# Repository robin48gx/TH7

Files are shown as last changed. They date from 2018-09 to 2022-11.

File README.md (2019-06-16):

# TH7
Code to read up to seven thermocouple inputs  from the raspberry pi using the SDS TH7 PCB

Enable spi in raspi-config.

Also, if you are running the pi as a user other than 'pi' add yourself to the spi group 
in /etc/group.

Clone the git hub repo here,

    $ git clone https://github.com/robin48gx/TH7.git 

change directory to TH7 and then run

    $ python ssh_terminal_TH7.py

The python file ssh_terminal_TH7.py is a simple terminal program
that displays the microvolts received from
the thermocouples and displays them in centigrade (for `k` type).
It also displays the PCB temperature and  the Vcc (voltage from USB to the pi;
the value is necessary for accurate calculation of microvolts).
It also creates a logging file (called 'TH7.log') showing the voltage supplied to the pi, the 
PCB temperature and the temperature of each connected thermocouple. This logs once per minute.
If logging is required run with nohup, i.e.

    $ nohup python TH7_logger.py > /dev/null & 
    
The logging will then continue on the pi even if the terminal running it is closed.
The LEDs are controlled by the ssh_terminal_TH7.py and by the TH7_logger.py programs, so if they are alternately blinking
this means the logging is continuing.
A script called 'plot_it.sh' will (using gnuplot) take data from the TH7.log file
and present it as a graph.

The python file thermometers_TH7.py adds to this with 
tkinter drawn thermometers. You may need the tkinter python 
modules for this : i.e. apt-get install python-tk.

Feel free to branch off this to make a temperature logger or a web interface.

For h/w 0.4 and above, an open thermocouple connection will display a very low 
micro-volts figure (typically < -7000) which is out of range for most thermocouples
and out of the range that most temperature readings would ever require (its below
abs zero for a k type for instance).
This means open thermocouples can be error flagged (as has been implemented for the
python `k` type thermocouple in this repo).

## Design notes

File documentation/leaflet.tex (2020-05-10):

%\documentclass[a4paper,10pt]{article}
\documentclass[10pt,foldmark]{leaflet}
\renewcommand*\foldmarkrule{.3mm}
\renewcommand*\foldmarklength{5mm}
\usepackage{qrcode}
\usepackage{amsmath}
\usepackage[T1]{fontenc}
\usepackage{textcomp}
\usepackage{mathptmx}
\usepackage[scaled=0.9]{helvet}
\usepackage[utf8]{inputenc}
\usepackage{graphicx}

%opening
\title{S.D.S. TH7: Seven Channel Thermocouple  Pi Hat}
\author{Scientific Data Systems}
\begin{document}
%\thispagestyle{empty} % get rid of page number does not work
\pagenumbering{gobble}
\maketitle
% \begin{abstract}
% This leaflet describes the TH7 generic thermocouple reader pi-hat/PCB for the Raspberry~Pi.
% \end{abstract}

\begin{figure}
 \centering
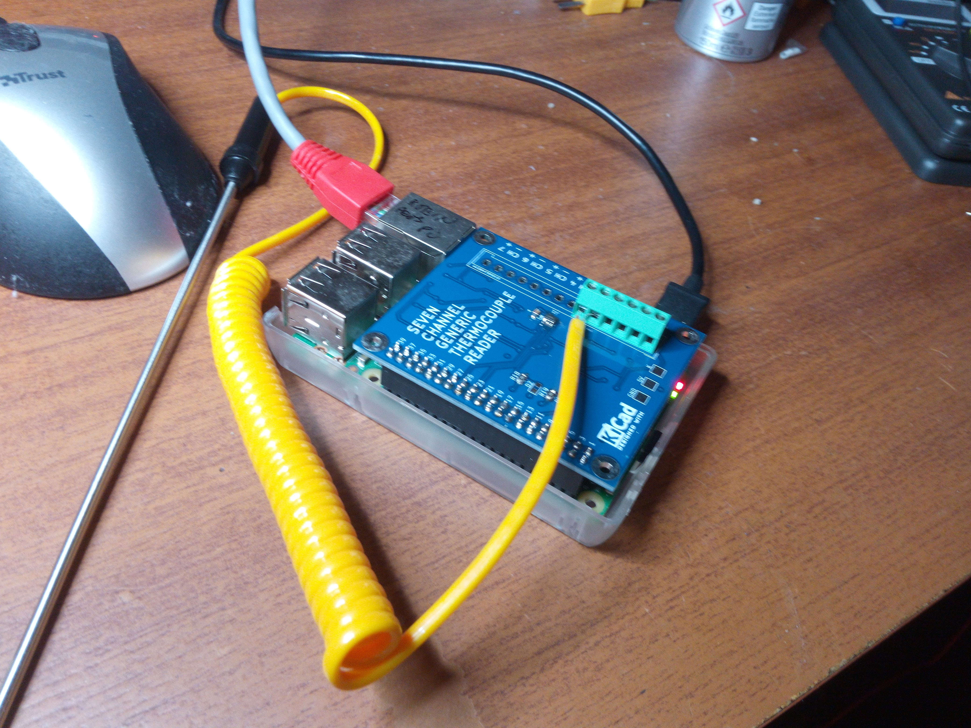
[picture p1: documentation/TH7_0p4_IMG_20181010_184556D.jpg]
 
 % TH7_0p4_IMG_20181010_184556D.jpg: 0x0 pixel, 300dpi, 0.00x0.00 cm, bb=
 \caption{TH7 with a `k' type probe fitted.}
 \label{fig:th7}
\end{figure}

\section{TH7 Description}
%
The TH7 is a Raspberry~Pi hat   that
provides seven thermocouple inputs(see figure~\ref{fig:th7}).
%
This means seven different temperatures can be read
simultaneously. 
%
Its possible uses are 
logging/monitoring and control of temperature sensitive processes.
%
With on-board PCB temperature measurement, 
the PCB temperature
is used to implement
full Cold~Junction~Compensation (CJC).
%
Uncalibrated, the TH7 gives a typical accuracy of $\pm$ ${2}^{\circ} C$.
%
The TH7 also provides two user programmable LEDs; and 
makes available the PCB temperature, and the supply voltage to the Raspberry~Pi (USB voltage can vary between 4.7 to 5.2).
\clearpage
The TH7 is a generic thermocouple reader, and therefore should work with any thermocouple type.
%
Software defines its micro-volt to temperature and CJC characteristics.
Software support has currently only been written for the `k' type.

%\clearpage
\subsection{Characteristics}
The TH7 offers:
\begin{itemize}
 \item Full cold junction compensation;
 \item Thermocouple disconnection or open-circuit  detection;
 \item Seven inputs;
 \item Uses the Rasberry~Pi standard python SPI interface;
 %\item Python coding examples \\ https://github.com/robin48gx/TH7;
 \item Two user programmable LEDs;
 \item On chip PCB temperature measurement;
  \item Can be used as a general-purpose micro-volt 
  reader with a range of $\approx -6000 \mu V \rightarrow 40000 \mu V$.
\end{itemize} 

\section{Instructions}
\subsection{Connection to terminal block}
%
Connect the thermocouples using the hital~tech connectors and ensure the wires make contact with the 
connector metal clamps (see figure~\ref{fig:con}).
%
\subsection{Conection to the device being measured}
%
Always apply insulation to the thermocouples (i.e. do not ground them).
%
Epoxy resin is often useful for gluing thermocouples to devices under long term temperature tests.

\begin{figure}[h]
 \centering
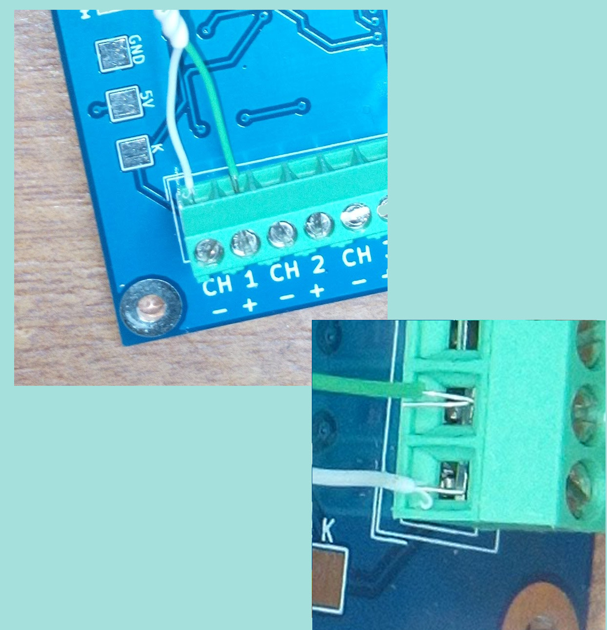
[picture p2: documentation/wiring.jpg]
 
 % wiring.JPG: 0x0 pixel, 300dpi, 0.00x0.00 cm, bb=
 \caption{Image shows wiring for European standard `k' type thermocouples wiring (green is plus and the white is minus; other countries may use different colour schemes.)
%
 If the thermocouple is inserted with incorrect polarity it will read incorrectly and temperature will be seen to go down when heat is applied.}
 \label{fig:con}
\end{figure}

\begin{figure}[h]
 \centering
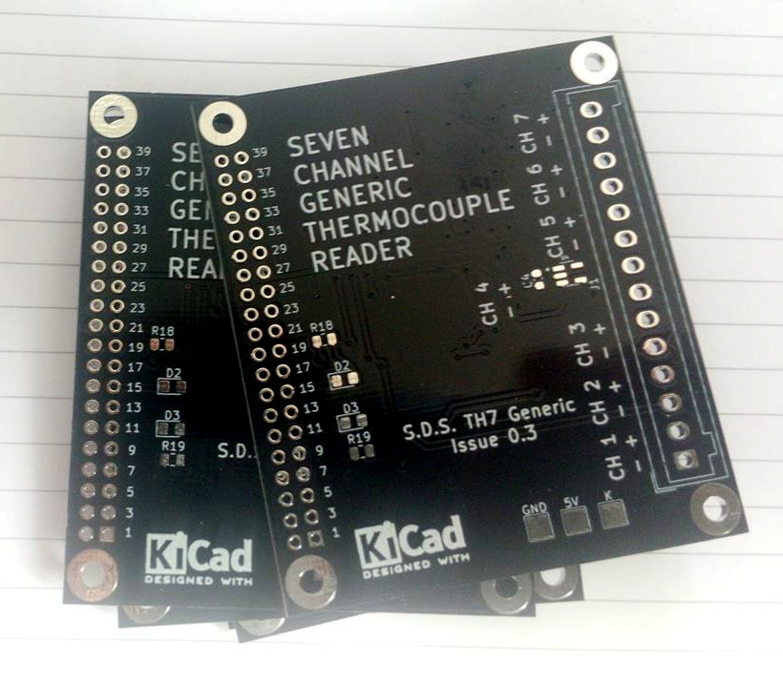
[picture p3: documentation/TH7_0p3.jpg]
 
 % TH7_0p3.jpg: 0x0 pixel, 300dpi, 0.00x0.00 cm, bb=
 \caption{TH7 thermocouple Interface PCB/Raspberry~Pi~Hat}
 \label{fig:th7_2}
\end{figure}

\clearpage
\begin{figure}[ht]
 \centering
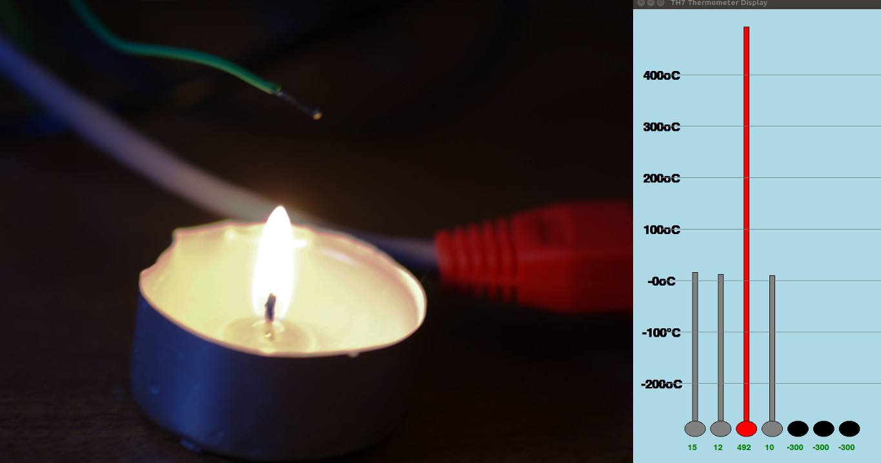
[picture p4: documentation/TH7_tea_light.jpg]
 
 % TH7_tea_light.JPG: 0x0 pixel, 300dpi, 0.00x0.00 cm, bb=
 \caption{Thermocouple over a tea light flame at circa ${500}^{\circ} C$.}
 \label{fig:pi}
\end{figure}
\mbox{}
\\
\\
\qrcode[height=1in]{http://www.scientificdatasystems.co.uk}
\\
\\
\vspace{0.5cm}
Contact: info@scientificdatasystems.co.uk
\\
\\
\qrcode[height=1in]{https://www.youtube.com/watch?v=EcGQWLSwX3U}
\\
\\
Youtube tutorial:
\\
https://www.youtube.com/watch?v=EcGQWLSwX3U
\vspace{0.5cm}
\clearpage

\section{What thermocouples are}

Thermocouples are two different types of metal wire welded together
at one end.
%
When there is a heat difference between two ends of the wire,
the two metals produce a small voltage.
%
This is typically very small, for `k' type thermocouples for instance,
this is about 40 millionths of a Volt per Centigrade change in temperature.
%
This voltage is so small that ordinary voltage reading chips, Analogue to Digital Converters (ADC),  cannot easily read them
to any reasonable accuracy.
%
The small signal is usually amplified
into a range that a computer chip (i.e. ADC) can read.
%
The TH7 has an amplifier that takes the small voltage and amplifies it by 100.
%
It can then be read into the Raspberry~Pi where it can be converted to
a temperature reading with adequate accuracy.
%
Wikipedia has a good entry on thermocouples.
https://en.wikipedia.org/wiki/Thermocouple.
%as a qrcode, \qrcode[height=1in]{https://en.wikipedia.org/wiki/Thermocouple}

\subsection{Cold Junction Compensation}

The tables and equations to convert thermocouple voltage to
temperature all assume that the instrument end is at zero centigrade.

Because the voltage read at the TH7 input is not at zero centigrade (well not normally!)
the junction of the wires {\em at the connector block}  makes a thermocouple itself, but in opposition to
the one at the measurement end.
%
For instance, with a `k' type thermocouple
the voltage read at $25^\circ C$ would read around $1000 \mu V$ low!

The TH7 has a temperature measurement chip placed right by the terminal block for the thermocouple inputs.
By knowing this temperature, the TH7 works out what the missing voltage is
and adds it in before calculating the final temperature. This is commonly known as cold junction compensation.

\subsection{Using the TH7 as a micro-volt reader}

The TH7 can be used as a general purpose micro-volt reader.
The voltage source must be floating i.e. not grounded.
A range of $\approx -6mV \rightarrow 40mV$ can be read.
\clearpage
\subsection{Availability}

TH7 boards are currently available with a four week lead time.
\\
\\
The TH7 is compatible with the Raspberry~Pi models 3 and 4.
\\
\\
TH7 boards may be customised for any thermocouple type.
An example for `k' type may be found on GITHUB 
\\
\\
\\
https://github.com/robin48gx/TH7 
\\
\\
\qrcode{https://github.com/robin48gx/TH7}
%\vspace{3.5cm}
%\clearpage
%\mbox{}
%\vfill
%\qrcode[height=1in]{http://www.scientificdatasystems.co.uk}
%\vspace{0.5cm}
\\
\\
\\
Contact: info@scientificdatasystems.co.uk
\\
\\
\qrcode[height=1in]{http://www.scientificdatasystems.co.uk}
\vspace{0.5cm}

\end{document}

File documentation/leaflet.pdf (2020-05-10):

What thermocouples are

Thermocouples are two different types of metal wire welded together at one end. When there is a heat difference between two ends of the wire, the two metals produce a small voltage. This is typically very small, for ‘k’ type thermocouples for instance, this is about 40 millionths of a Volt per Centigrade change in temperature. This voltage is so small that ordinary voltage reading chips, Analogue to Digital Converters (ADC), cannot easily read them to any reasonable accuracy. The small signal is usually amplified into a range that a computer chip (i.e. ADC) can read. The TH7 has an amplifier that takes the small voltage and amplifies it by 100. It can then be read into the Raspberry Pi where it can be converted to a temperature reading with adequate accuracy. Wikipedia has a good entry on thermocouples. https://en.wikipedia.org/wiki/Thermocouple.

Cold Junction Compensation

The tables and equations to convert thermocouple voltage to temperature all assume that the instrument end is at zero centigrade.

Because the voltage read at the TH7 input is not at zero centigrade (well not normally!) the junction of the wires at the connector block makes a thermocouple itself, but in opposition to the one at the measurement end. For instance, with a ‘k’ type thermocouple the voltage read at 25◦C would read around 1000µV low!

The TH7 has a temperature measurement chip placed right by the terminal block for the thermocouple inputs. By knowing this temperature, the TH7 works out what the missing voltage is and adds it in before calculating the final temperature. This is commonly known as cold junction compensation.

Using the TH7 as a micro-volt reader

The TH7 can be used as a general purpose micro-volt
reader. | The voltage source must be floating i.e. | not
grounded. A range of ≈ −6mV → 40mV can be read.

Availability

TH7 boards are currently available with a four week lead time.

The TH7 is compatible with the Raspberry Pi models 3 and 4.

TH7 boards may be customised for any thermocouple type. An example for ‘k’ type may be found on GITHUB

https://github.com/robin48gx/TH7

Contact: info@scientificdatasystems.co.uk

# S.D.S. TH7: Seven Channel Thermocouple Pi Hat

Scientific Data Systems

May 10, 2020

TH7 Description

The TH7 is a Raspberry Pi hat that provides seven thermocouple inputs(see figure 1). This means seven different temperatures can be read simultaneously. Its possible uses are logging/monitoring and control of temperature sensitive processes. With on-board PCB temperature measurement, the PCB temperature is used to implement full Cold Junction Compensation (CJC). Uncalibrated, the TH7 gives a typical accuracy of ± 2

◦C. The TH7 also provides two user programmable LEDs; and makes available the PCB temperature, and the supply voltage to the Raspberry Pi (USB voltage can vary between 4.7 to 5.2).


Figure 1: TH7 with a ‘k’ type probe fitted.

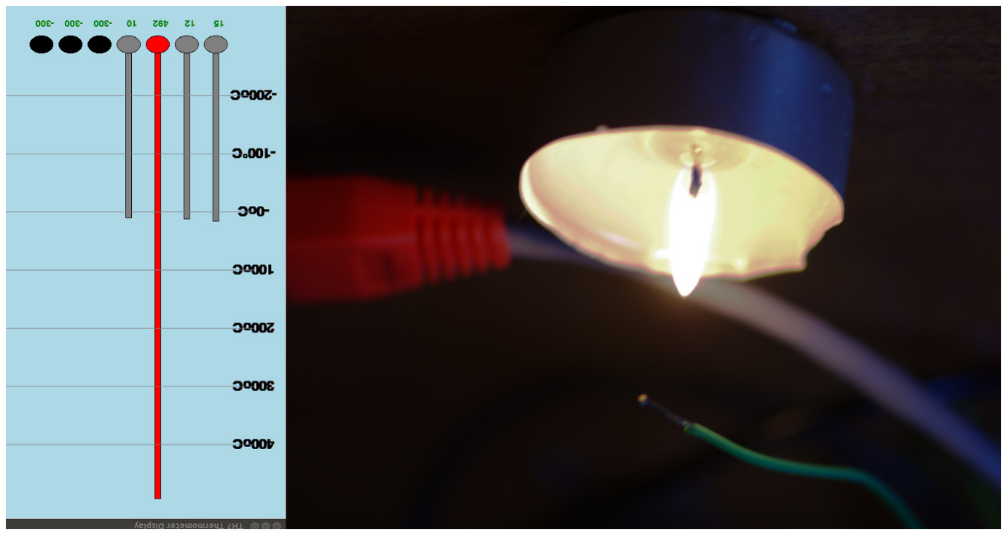
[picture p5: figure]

The TH7 is a generic thermocouple reader, and therefore

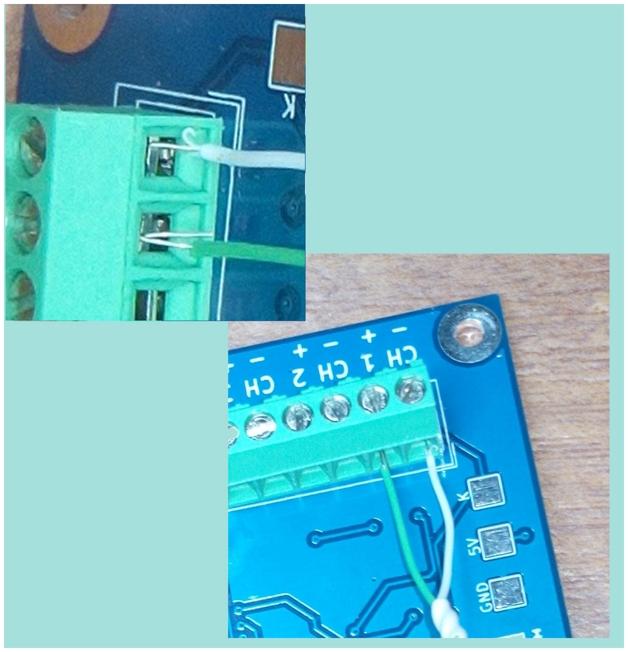
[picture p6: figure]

should work with any thermocouple type. Software defines its micro-volt to temperature and CJC characteristics.

Software support has currently only been written for the ‘k’

type.

Characteristics

The TH7 offers:

Full cold junction compensation; •

Thermocouple disconnection or open-circuit detection; •

Seven inputs; •

Uses the Rasberry Pi standard python SPI interface; •

Two user programmable LEDs; •

On chip PCB temperature measurement; •

Can be used as a general-purpose micro-volt reader with •

. Vµ 40000 →Vµ 6000 ≈ − a range of

Instructions

Connection to terminal block

Connect the thermocouples using the hital tech connectors and ensure the wires make contact with the connector metal

clamps (see figure 2).

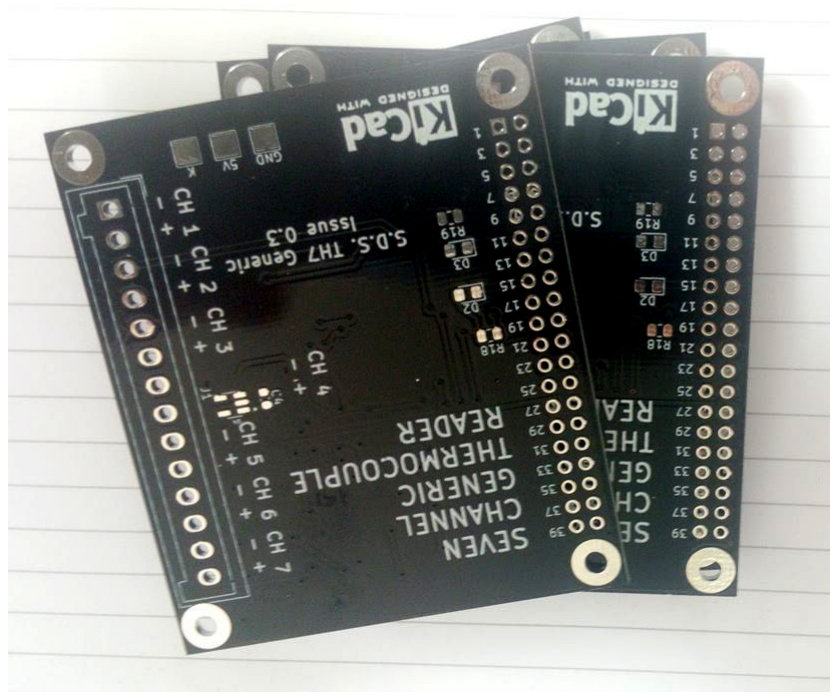
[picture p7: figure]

Conection to the device being measured

Always apply insulation to the thermocouples (i.e. do not ground them). Epoxy resin is often useful for gluing thermocouples to devices under long term temperature tests.

Figure 2: Image shows wiring for European standard ‘k’ type thermocouples wiring (green is plus and the white is minus; other countries may use different colour schemes.)

If the thermocouple is inserted with incorrect polarity it will read incorrectly and temperature will be seen to go down

when heat is applied.

Figure 3: TH7 thermocouple Interface

PCB/Raspberry Pi Hat

Figure 4: Thermocouple over a tea light flame at circa

500◦
. C

Contact: info@scientificdatasystems.co.uk

Youtube tutorial:

https://www.youtube.com/watch?v=EcGQWLSwX3U

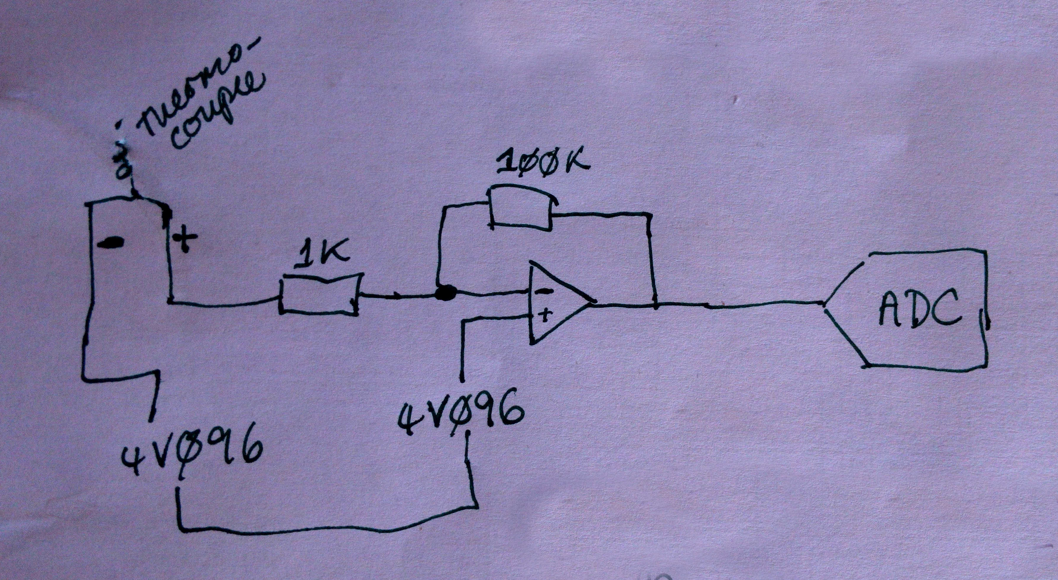
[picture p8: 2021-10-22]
kicad/circuit_drawing.jpg

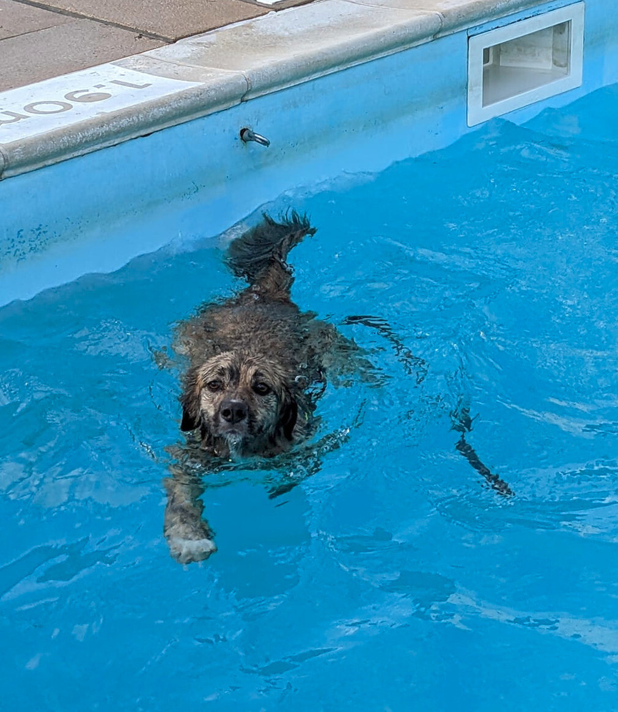
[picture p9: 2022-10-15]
gui_exp/dog.png

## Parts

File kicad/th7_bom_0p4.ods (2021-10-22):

Source: | /home/robin/projects/th7/kicad/test.sch
Date: | Fri 14 Dec 2018 08:12:14 GMT
Tool: | Eeschema 6.0.0-rc1-unknown-46fddab~66~ubuntu16.04.1
Component Count: | 40
ROWS HIGHLIGHTED ARE COMPONENTS MOUNTED ON TOP OF PCB (top has text “SEVEN CHANNEL THERMOCOUPLE READER”) |  |  |  |  |  | Supplied # | Part Code
All resistors are 50ppm per oC and 1%
Ref | Value | Footprint | Datasheet | Manufacturer | Vendor | Num supplied
C1 | 100nF | Capacitor_SMD:C_0603_1608Metric | ~ |  |  | ~=50 | F233-2715
C2 | 100nF | Capacitor_SMD:C_0603_1608Metric | ~ |  |  | “ | “
C3 | 100nF | Capacitor_SMD:C_0603_1608Metric | ~ |  |  | “ | “
C4 | 100nF | Capacitor_SMD:C_0603_1608Metric | ~ |  |  | “ | “
D1 | LM4040DBZ-4.1 | Package_TO_SOT_SMD:SOT-23 | http://www.ti.com/lit/ds/symlink/lm4040-n.pdf |  |  | ~=40 | F1468837RL
D2 | LED_ALT | LED_SMD:LED_0805_2012Metric_Pad1.15x1.40mm_HandSolder | ~ |  |  | 200 | Rs861-0175
D3 | LED_ALT | LED_SMD:LED_0805_2012Metric_Pad1.15x1.40mm_HandSolder | ~ |  |  | 200 | Rs692-1170
J1 | Screw_Terminal_01x14 | Connector_Wago:Wago_734-144_1x14_P3.50mm_Vertical | ~ |  |  | 7 && 6 | HITAL TECH MTS-06008 && 2 times MTS-02008
R1 | 680 Ohm (or 470) | Resistor_SMD:R_0805_2012Metric | ~ |  |  | 1000 | RS804-6423
R2 | 10k | Resistor_SMD:R_0805_2012Metric | ~ |  |  | 100 | F150-0664
R3 | 10k | Resistor_SMD:R_0805_2012Metric | ~ |  |  | “ | “
R4 | 100K | Resistor_SMD:R_0805_2012Metric | ~ |  |  | 100 | F150-0665
R5 | 100K | Resistor_SMD:R_0805_2012Metric | ~ |  |  | “ | “
R6 | 100K | Resistor_SMD:R_0805_2012Metric | ~ |  |  | “ | “
R7 | 100K | Resistor_SMD:R_0805_2012Metric | ~ |  |  | “ | “
R8 | 100K | Resistor_SMD:R_0805_2012Metric | ~ |  |  | “ | “
R9 | 100K | Resistor_SMD:R_0805_2012Metric | ~ |  |  | “ | “
R10 | 100K | Resistor_SMD:R_0805_2012Metric | ~ |  |  | “ | “
R11 | 1K | Resistor_SMD:R_0805_2012Metric | ~ |  |  | 100 | F150663
R12 | 1k | Resistor_SMD:R_0805_2012Metric | ~ |  |  | “ | “
R13 | 1k | Resistor_SMD:R_0805_2012Metric | ~ |  |  | “ | “
R14 | 1k | Resistor_SMD:R_0805_2012Metric | ~ |  |  | “ | “
R15 | 1k | Resistor_SMD:R_0805_2012Metric | ~ |  |  | “ | “
R16 | 1k | Resistor_SMD:R_0805_2012Metric | ~ |  |  | “ | “
R17 | 1k | Resistor_SMD:R_0805_2012Metric | ~ |  |  | “ | “
R18 | 330 | Resistor_SMD:R_0805_2012Metric | ~ |  |  | 150 | F933-4351
R19 | 330 | Resistor_SMD:R_0805_2012Metric | ~ |  |  | “ | “
R25 | 10K | Resistor_SMD:R_0603_1608Metric_Pad1.05x0.95mm_HandSolder | ~ |  |  | ok | F150-0664
R31 | 330k | Resistor_SMD:R_0805_2012Metric | ~ |  |  | ~=50 | F465-2983
R32 | 330k | Resistor_SMD:R_0805_2012Metric | ~ |  |  | “ | F150-0664
R33 | 330k | Resistor_SMD:R_0805_2012Metric | ~ |  |  | “ | “
R34 | 330k | Resistor_SMD:R_0805_2012Metric | ~ |  |  | “ | “
R35 | 330k | Resistor_SMD:R_0805_2012Metric | ~ |  |  | “ | “
R36 | 330k | Resistor_SMD:R_0805_2012Metric | ~ |  |  | “ | “
R37 | 330k | Resistor_SMD:R_0805_2012Metric | ~ |  |  | “ | “
RASPI_2_3_HEADER1 | Raspberry_Pi_2_3 | Connector_PinSocket_2.54mm:PinSocket_2x20_P2.54mm_Vertical | https://www.raspberrypi.org/documentation/hardware/raspberrypi/schematics/rpi_SCH_3bplus_1p0_reduced.pdf |  |  | 9 | RS674-2369
U1 | MCP6074-E_SL | Package_SO:SOIC-14_3.9x8.7mm_P1.27mm | 1.57 USD |  |  | 3 | F1715858
U2 | MCP6074-E_SL | Package_SO:SOIC-14_3.9x8.7mm_P1.27mm | 1.57 USD |  |  | “ | F1715858
U3 | MCP3208 | Package_SO:SOIC-16W_5.3x10.2mm_P1.27mm | http://ww1.microchip.com/downloads/en/DeviceDoc/21298c.pdf |  |  | 0 | F1852020
U4 | TC77 | SOT95P280X145-5N:SOT95P280X145-5N | http://www.ti.com/lit/ds/symlink/tlv700.pdf |  |  | 0 | F1605583
PCB SDS TH7 ver 0.4

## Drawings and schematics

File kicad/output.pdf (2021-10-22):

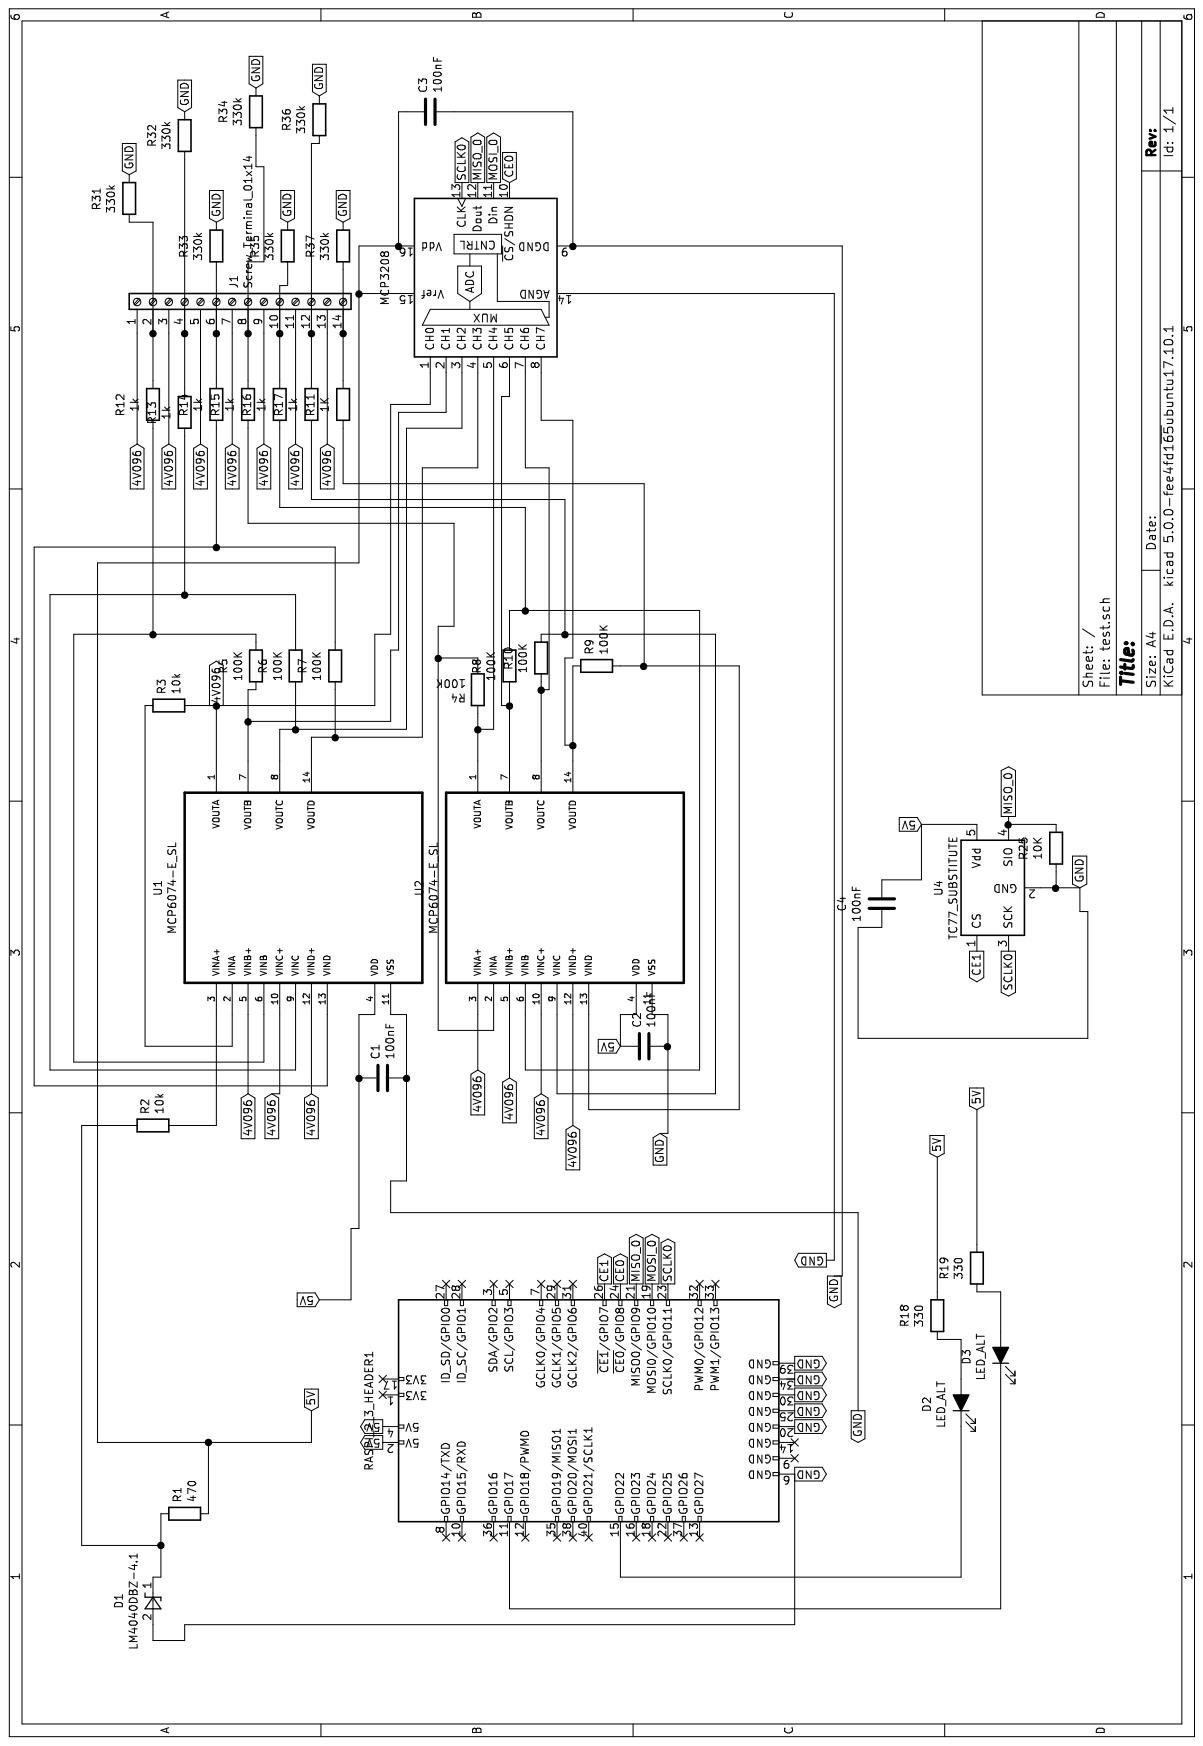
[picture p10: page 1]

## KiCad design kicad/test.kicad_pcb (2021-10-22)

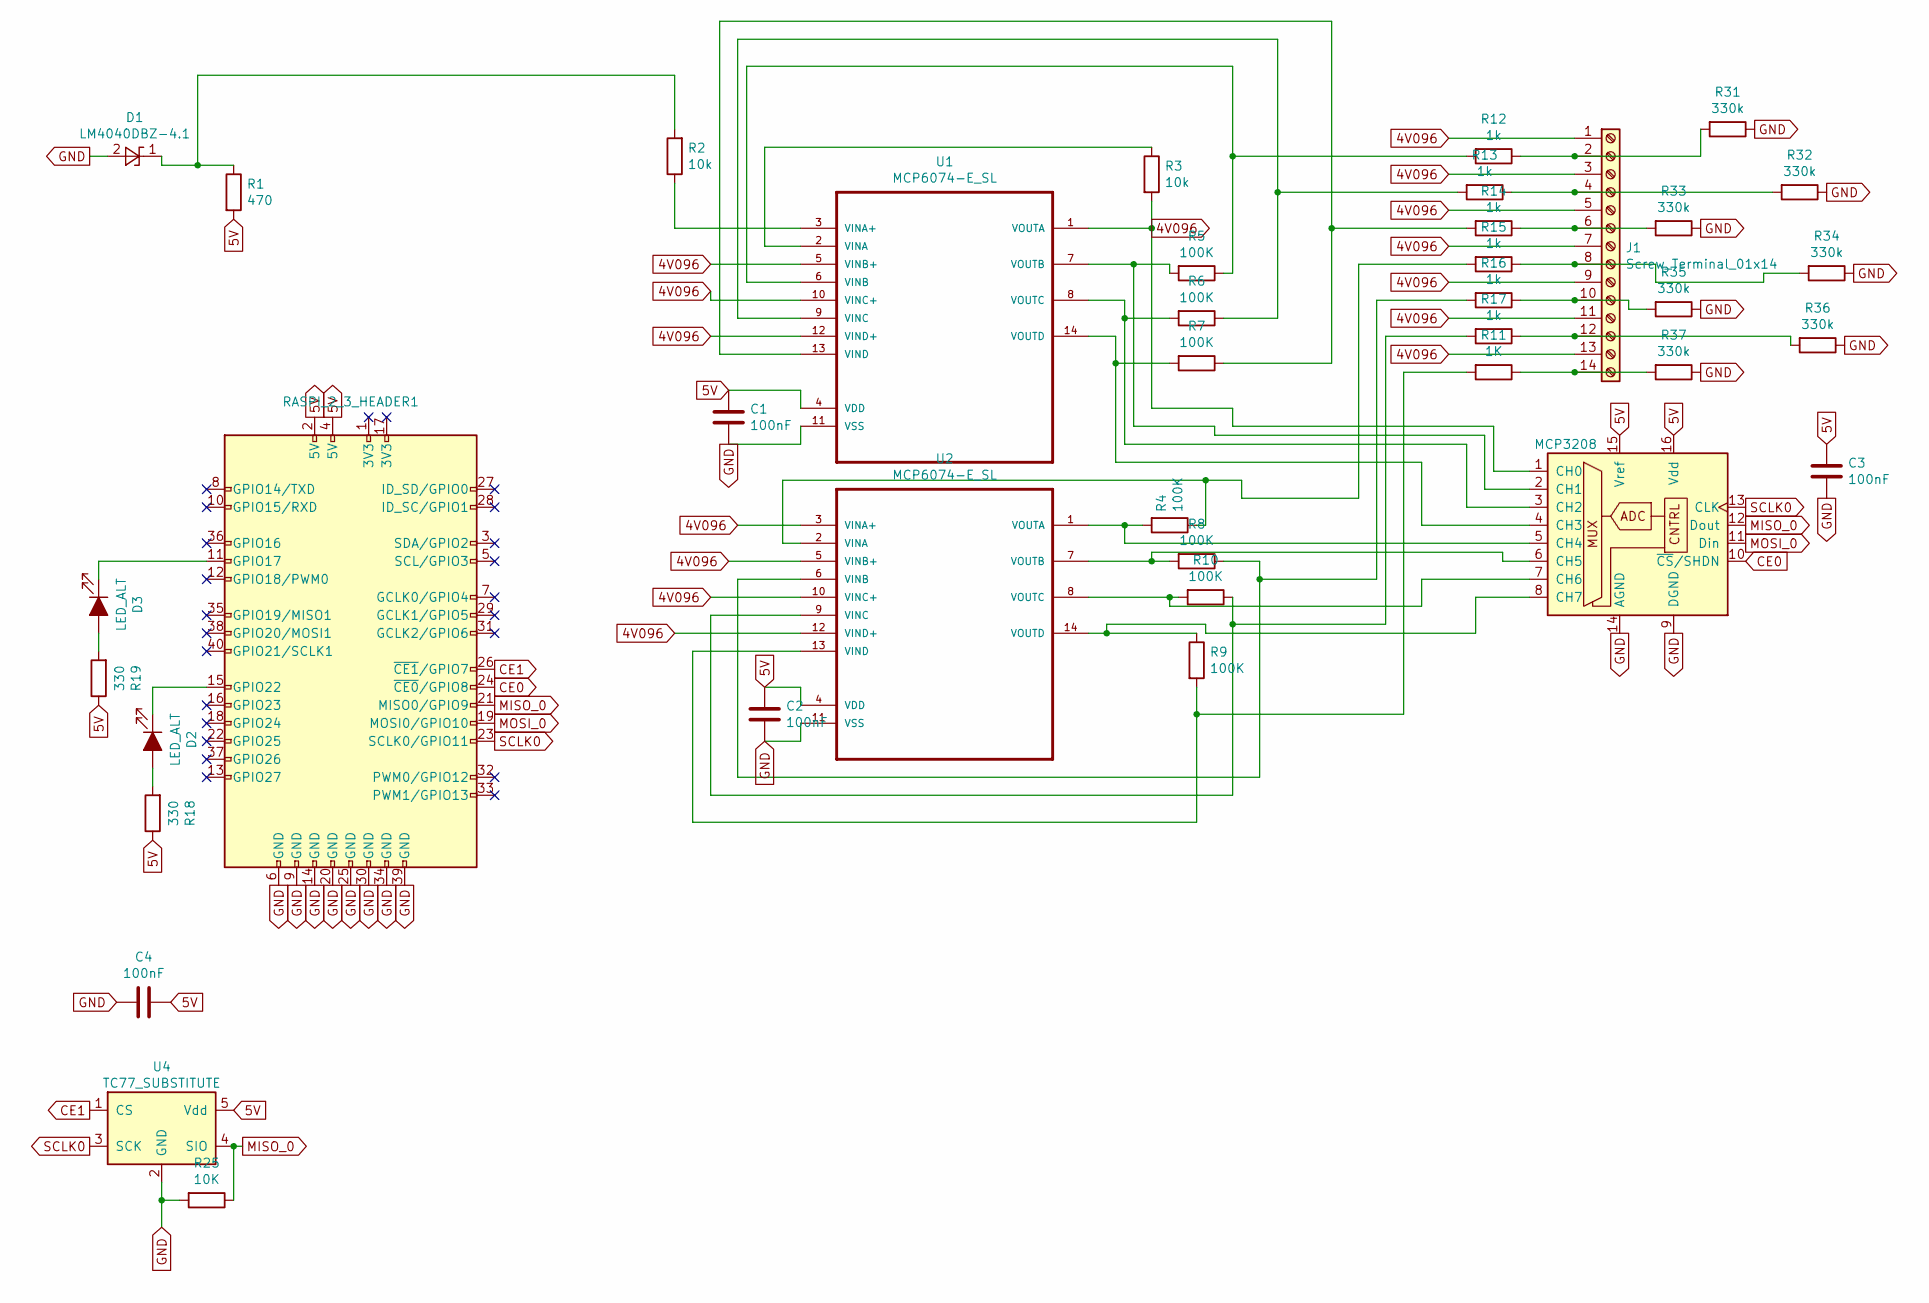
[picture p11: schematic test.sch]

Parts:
C1, C2, C3, C4: 100nF; C_0603_1608Metric
D1: LM4040DBZ-4.1; SOT-23
D2, D3: LED_ALT; LED_0805_2012Metric_Pad1.15x1.40mm_HandSolder
J1: Screw_Terminal_01x14; Wago_734-144_1x14_P3.50mm_Vertical
R1: 470; R_0805_2012Metric
R2, R3: 10k; R_0805_2012Metric
R4, R5, R6, R7, R8, R9, R10: 100K; R_0805_2012Metric
R11: 1K; R_0805_2012Metric
R12, R13, R14, R15, R16, R17: 1k; R_0805_2012Metric
R18, R19: 330; R_0805_2012Metric
R25: 10K; R_0603_1608Metric_Pad1.05x0.95mm_HandSolder
R31, R32, R33, R34, R35, R36, R37: 330k; R_0805_2012Metric
RASPI_2_3_HEADER1: Raspberry_Pi_2_3; PinSocket_2x20_P2.54mm_Vertical
U1, U2: MCP6074-E_SL; SOIC-14_3.9x8.7mm_P1.27mm
U3: MCP3208; SOIC-16W_5.3x10.2mm_P1.27mm
U4: TC77_SUBSTITUTE; SOT95P280X145-5N

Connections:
4V096: J1.1, J1.3, J1.5, J1.7, J1.9, J1.11, J1.13, R3.2, U1.1 (VOUTA), U1.5 (VINB+), U1.10 (VINC+), U1.12 (VIND+), U2.3 (VINA+), U2.5 (VINB+), U2.10 (VINC+), U2.12 (VIND+), U3.1 (CH0); also elsewhere on the board
5V: C1.1, C2.1, C3.1, C4.1, R1.2, R18.1, R19.1, RASPI_2_3_HEADER1.2 (5V), RASPI_2_3_HEADER1.4 (5V), U1.4 (VDD), U2.4 (VDD), U3.15 (Vref), U3.16 (Vdd), U4.5 (Vdd); also elsewhere on the board
CE0: RASPI_2_3_HEADER1.24 (~CE0~/GPIO8), U3.10 (~CS~/SHDN)
CE1: RASPI_2_3_HEADER1.26 (~CE1~/GPIO7), U4.1 (CS)
MISO_0: R25.1, RASPI_2_3_HEADER1.21 (MISO0/GPIO9), U3.12 (Dout), U4.4 (SIO)
MOSI_0: RASPI_2_3_HEADER1.19 (MOSI0/GPIO10), U3.11 (Din)
unnamed: D1.1 (K), R1.1, R2.2
unnamed: D2.1 (K), RASPI_2_3_HEADER1.15 (GPIO22)
unnamed: D2.2 (A), R18.2
unnamed: D3.1 (K), RASPI_2_3_HEADER1.11 (GPIO17)
unnamed: D3.2 (A), R19.2
unnamed: J1.2, R12.1, R31.2
unnamed: J1.4, R13.1, R32.2
unnamed: J1.6, R14.1, R33.2
unnamed: J1.8, R15.1, R34.2
unnamed: J1.10, R16.1, R35.2
unnamed: J1.12, R17.1, R36.2
unnamed: J1.14, R11.1, R37.2
unnamed: R2.1, U1.3 (VINA+)
unnamed: R3.1, U1.2 (VINA)
unnamed: R4.2, U2.1 (VOUTA), U3.5 (CH4)
unnamed: R5.2, U1.7 (VOUTB), U3.2 (CH1)
unnamed: R6.2, U1.8 (VOUTC), U3.3 (CH2)
unnamed: R7.2, U1.14 (VOUTD), U3.4 (CH3)
unnamed: R8.2, U2.7 (VOUTB), U3.6 (CH5)
unnamed: R9.1, U2.14 (VOUTD), U3.8 (CH7)
unnamed: R10.1, R17.2, U2.9 (VINC)
unnamed: R10.2, U2.8 (VOUTC), U3.7 (CH6)
unnamed: R9.2, R11.2, U2.13 (VIND)
unnamed: R5.1, R12.2, U1.6 (VINB)
unnamed: R6.1, R13.2, U1.9 (VINC)
unnamed: R7.1, R14.2, U1.13 (VIND)
unnamed: R4.1, R15.2, U2.2 (VINA)
unnamed: R8.1, R16.2, U2.6 (VINB)
SCLK0: RASPI_2_3_HEADER1.23 (SCLK0/GPIO11), U3.13 (CLK), U4.3 (SCK)

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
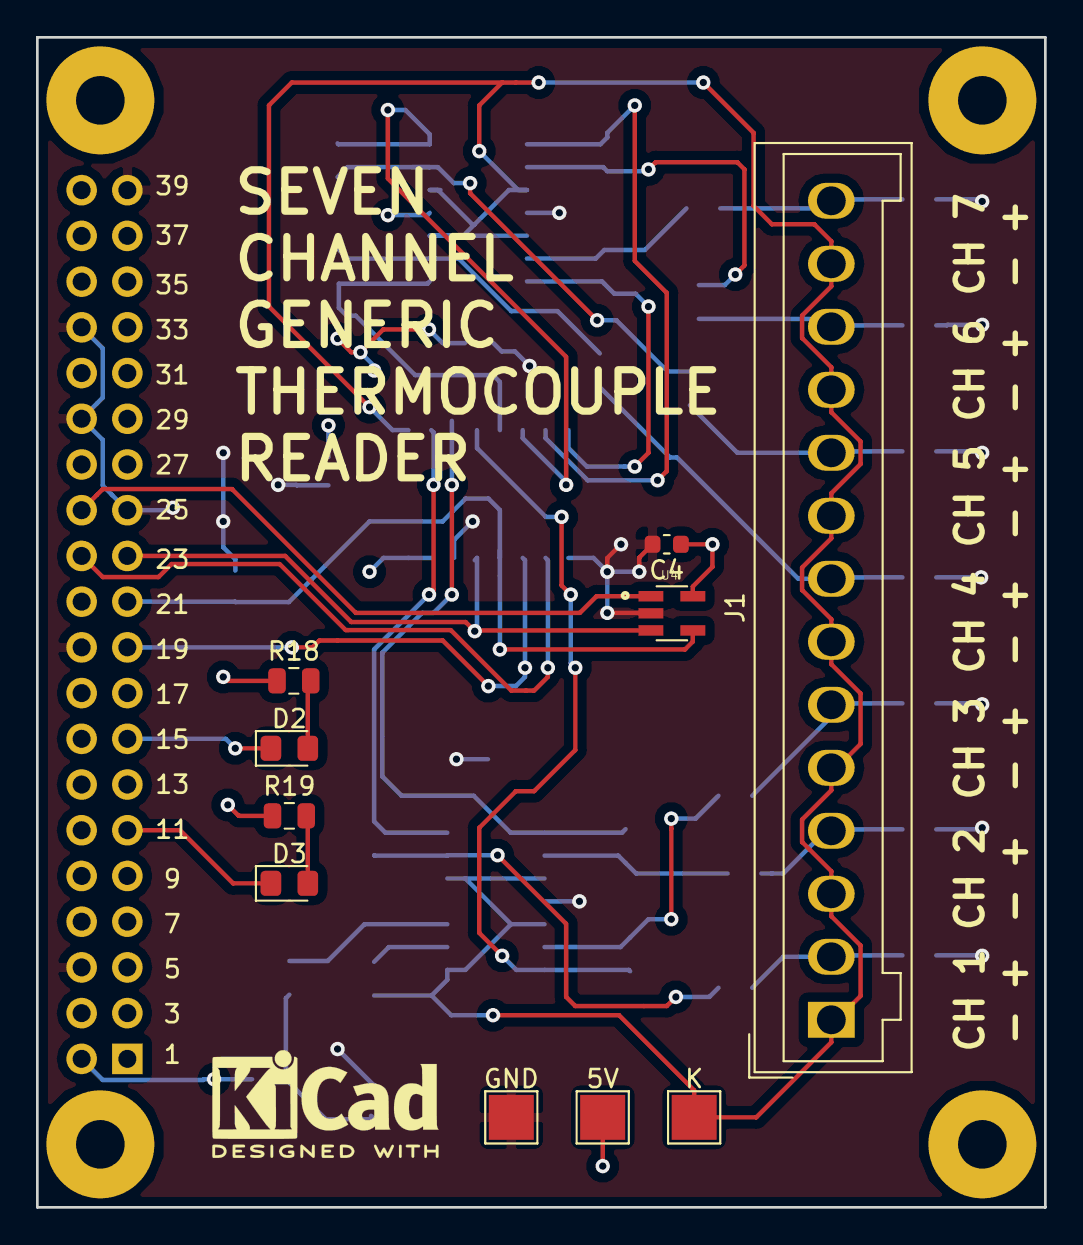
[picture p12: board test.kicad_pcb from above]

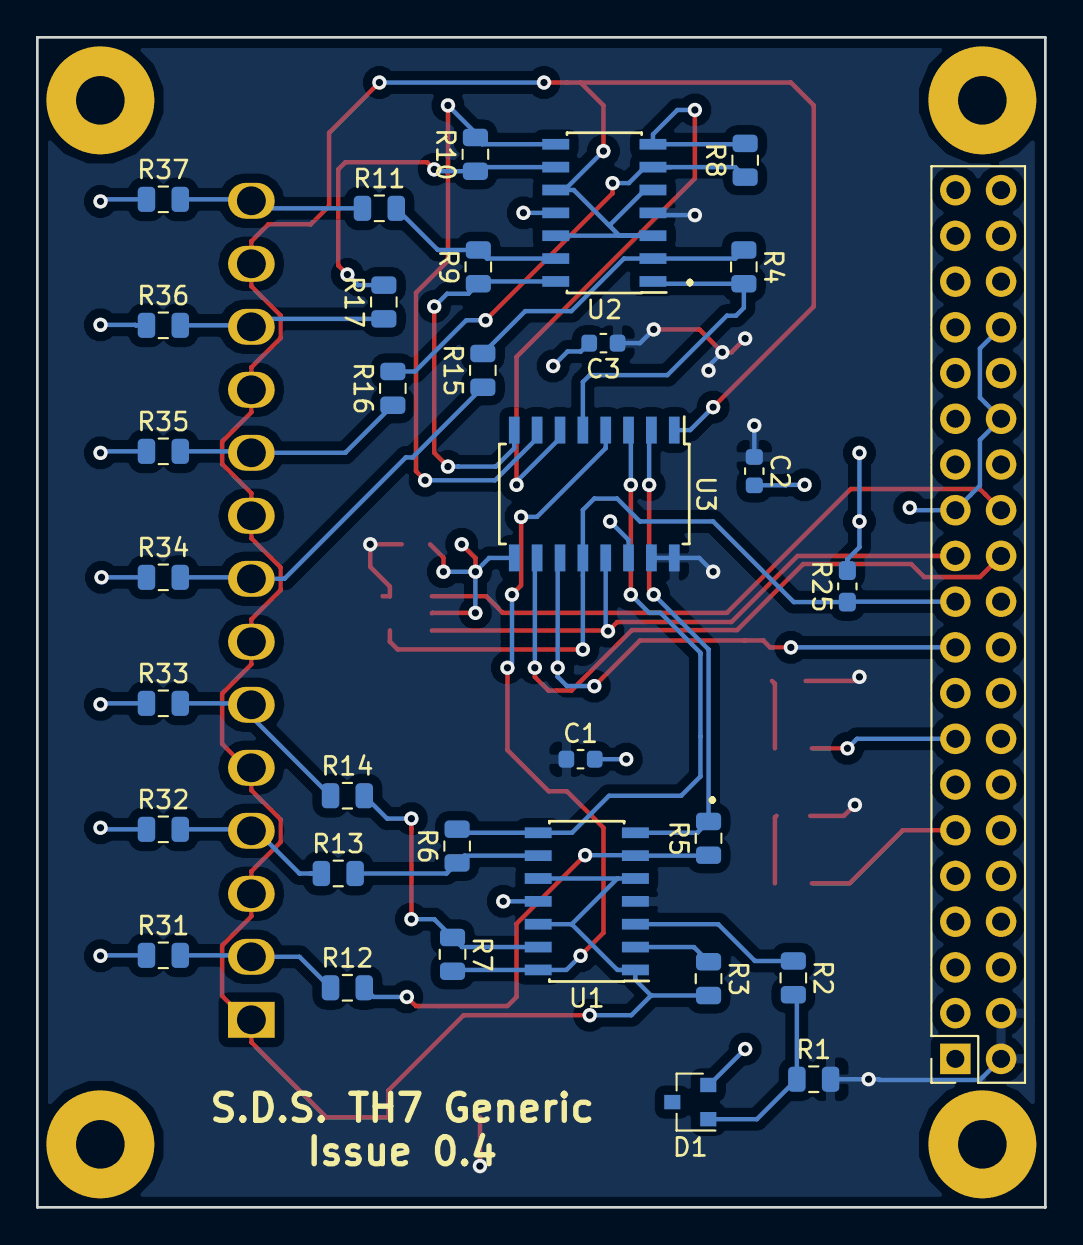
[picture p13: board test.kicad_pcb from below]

Board: 2 copper layers, 56.0 x 65.0 mm, 43 parts (33 on the bottom side), 36 nets.

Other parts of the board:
5V: TestPoint_Pad_2.5x2.5mm
GND: TestPoint_Pad_2.5x2.5mm
K: TestPoint_Pad_2.5x2.5mm

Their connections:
4V096: K.1; also elsewhere on the board
5V: 5V.1; also elsewhere on the board

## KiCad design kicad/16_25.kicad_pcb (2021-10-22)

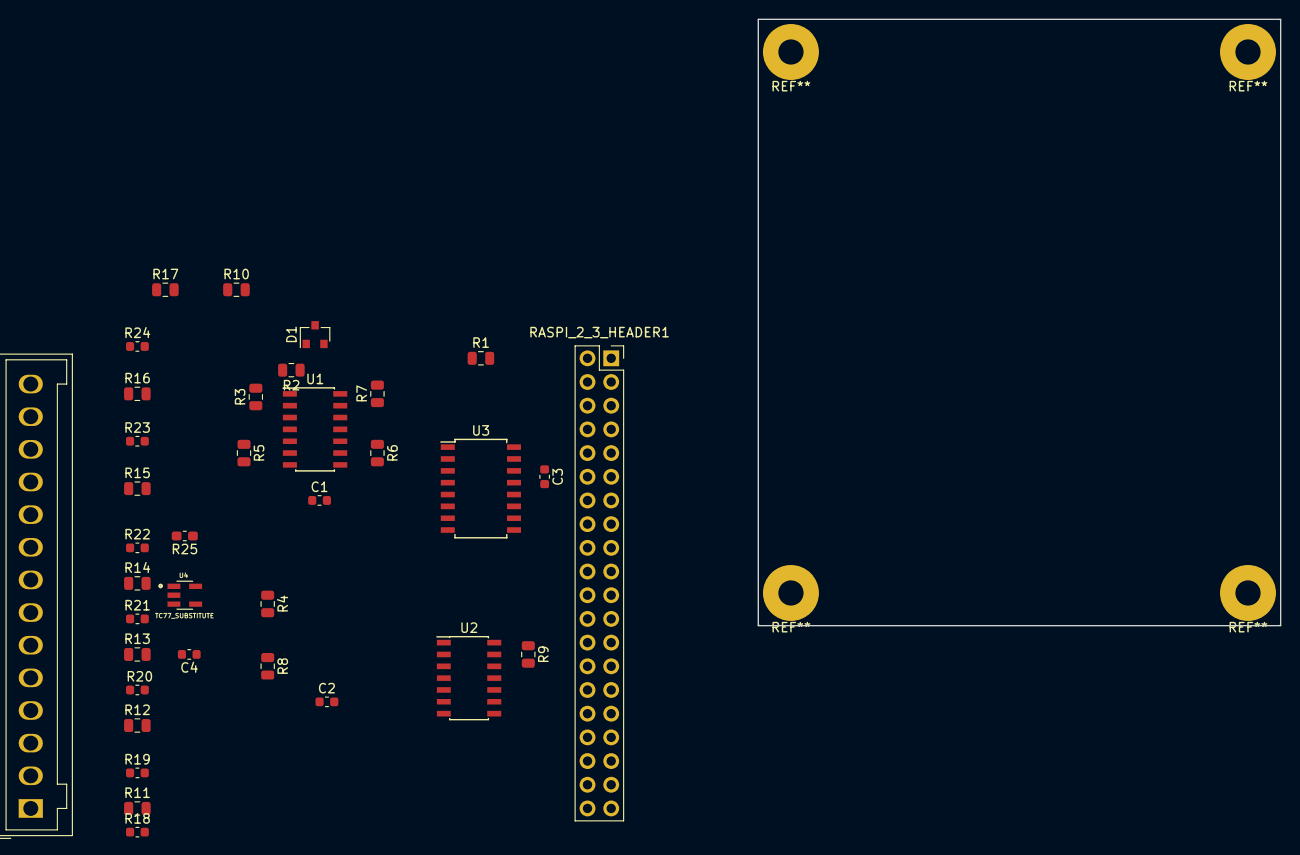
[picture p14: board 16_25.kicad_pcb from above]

Board: 2 copper layers, 56.0 x 65.0 mm, 36 parts (0 on the bottom side), 44 nets, no tracks yet.

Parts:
C1, C2, C3, C4: 100nF; C_0603_1608Metric
D1: LM4040DBZ-4.1; SOT-23
J1: Screw_Terminal_01x14; Wago_734-144_1x14_P3.50mm_Vertical
R1: 470; R_0805_2012Metric
R2, R3: 10k; R_0805_2012Metric
R4: 200K; R_0805_2012Metric
R5, R6, R7: 100K; R_0805_2012Metric
R8, R10: 200k; R_0805_2012Metric
R9: 500k; R_0805_2012Metric
R11: 1K; R_0805_2012Metric
R12, R13, R14, R15, R16, R17: 1k; R_0805_2012Metric
R18, R19, R20, R21, R22, R23, R24: 500K; R_0603_1608Metric
R25: 10K; R_0603_1608Metric_Pad1.05x0.95mm_HandSolder
RASPI_2_3_HEADER1: Raspberry_Pi_2_3; PinSocket_2x20_P2.54mm_Vertical
U1, U2: MCP6074-E_SL; SOIC-14_3.9x8.7mm_P1.27mm
U3: MCP3208; SOIC-16W_5.3x10.2mm_P1.27mm
U4: TC77_SUBSTITUTE; SOT95P280X145-5N

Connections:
4V096: R3.2, R18.2, R19.2, R20.2, R21.2, R22.2, R23.2, R24.2, U1.1, U1.5, U1.10, U1.12, U2.3, U2.5, U2.10, U2.12, U3.1
unnamed: C1.1, C2.1, RASPI_2_3_HEADER1.4, RASPI_2_3_HEADER1.39, U1.4, U2.4
unnamed: C1.2, C2.2, RASPI_2_3_HEADER1.25, U1.11, U2.11
unnamed: C3.1, C4.1, R1.2, RASPI_2_3_HEADER1.2, U3.15, U3.16, U4.5
unnamed: C3.2, RASPI_2_3_HEADER1.30, U3.9
unnamed: C4.2, R25.2, RASPI_2_3_HEADER1.20, U4.2
unnamed: D1.1, R1.1, R2.2
unnamed: D1.2, RASPI_2_3_HEADER1.6
unnamed: J1.1, R18.1
unnamed: J1.2, R11.1
unnamed: J1.3, R19.1
unnamed: J1.4, R12.1
unnamed: J1.5, R20.1
unnamed: J1.6, R13.1
unnamed: J1.7, R21.1
unnamed: J1.8, R14.1
unnamed: J1.9, R22.1
unnamed: J1.10, R15.1
unnamed: J1.11, R23.1
unnamed: J1.12, R16.1
unnamed: J1.13, R24.1
unnamed: J1.14, R17.1
unnamed: R2.1, U1.3
unnamed: R3.1, U1.2
unnamed: R4.1, U2.1, U3.5
unnamed: R5.2, U1.7, U3.2
unnamed: R6.2, U1.8, U3.3
unnamed: R7.2, U1.14, U3.4
unnamed: R8.2, U2.7
unnamed: R9.1, U2.14
unnamed: R10.1, R17.2, U2.9, U3.7
unnamed: R10.2, U2.8
unnamed: R9.2, R11.2, U2.13, U3.8
unnamed: R5.1, R12.2, U1.6
unnamed: R6.1, R13.2, U1.9
unnamed: R7.1, R14.2, U1.13
unnamed: R4.2, R15.2, U2.2
unnamed: R8.1, R16.2, U2.6, U3.6
unnamed: R25.1, RASPI_2_3_HEADER1.21, U3.12, U4.4
unnamed: RASPI_2_3_HEADER1.19, U3.11
unnamed: RASPI_2_3_HEADER1.23, U3.13, U4.3
unnamed: RASPI_2_3_HEADER1.24, U3.10
unnamed: RASPI_2_3_HEADER1.26, U4.1
unnamed: RASPI_2_3_HEADER1.34, U3.14

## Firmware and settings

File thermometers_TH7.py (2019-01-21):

#! /usr/bin/python
import sys
import time
import Tkinter	# requires python-tk (apt-get install python-tk)
from Tkinter import *
import random
import math
import os
import spidev
import time
import RPi.GPIO as GPIO

#
# TH7 thermocouple reader for the raspberry pi
#
# The array below `temps' holds the temperatures calculated
# in centigrade
#
temps = [ 20.3,20.3,20.3,20.3,20.3,20.3,20.3 ]

# start of the thermometers at bottom of page
ybase = 600

# set up the I/O to read the thermocouples
#
spi = spidev.SpiDev()  # spi instance to read 12 bit ADC	
spi_tc77 = spidev.SpiDev() # spi instance to read TC77 digital temperature chip
spi.open(0, 0)
spi_tc77.open(0,1)
spi.max_speed_hz =  10000
spi_tc77.max_speed_hz =  10000
# create spi object
# open spi port 0, device (CS) 0
GPIO.setmode(GPIO.BCM)
GPIO.setwarnings(False)
GPIO.setup(22, GPIO.OUT) # D2 LED   
GPIO.setup(17, GPIO.OUT) # D3 LED
GPIO.output(22,GPIO.HIGH) # D2 LED OFF
GPIO.output(17,GPIO.LOW) # D3 LED ON
led_counter=0
pcb_temp = 25.0
channels = [0,0,0,0,0,0,0,0]
vadj =1.0
vadj_now=1.0
vref=0.0
# compress movement for thermometers
#

def tcompress ( t ):
   if t < -55:
      t = ((t+55)/5 - 55)
   if t > 120:
      t = (t/5 + 96)
   return t



# assume kelvin input
#
def tcompressk ( t ):
    return tcompress(t -273.15)*2

# print the micro-volts, voltage supplied to pi and the voltage adjustment factors
# onto a terminal
#
def print_list():
    global pcb_temp
    for i in range(1, len(channels)):
        uv = channels[i] + (k_type_translate_c(pcb_temp))
        if uv < -6500:
          print ('channel: %d\t %.3f uV \t %.3f oC (K-type) ERROR' % (i, uv, k_type_translate_uv(uv))) 
        else:
          print ('channel: %d\t %.3f uV \t %.3f oC (K-type)' % (i, uv, k_type_translate_uv(uv)))
        temps[i-1] = k_type_translate_uv(uv) # for the gui thermomemters
    print "vadj:    \t%2f" % vadj
    print "vadj_now: %2f  Pi Vdd %f" % (vadj_now, 5.0/vadj)
    #print "PCB_TEMP: %2f" % pcb_temp
    print "PCB_TEMP %2foC uV:\t%2f\t(%2f C)" % (pcb_temp,k_type_translate_c(pcb_temp), k_type_translate_uv(k_type_translate_c(pcb_temp)))


# ITS-90 thermocouple polynomial equations to translate temperature oC to microvolts
# for `k' type thermocouples
#
#
def k_type_translate_c(temp):
    c0 =  c1 =  c2 =  c3 =  c4 =  c5 =  c6 =  c7 =  c8 =  c9 =  c10 = 0.0
    t = et = mikrovolts = 0.0

    a0 = 1.185976e2
    a1 = -1.183432e-4

    if (temp < 0.0):
        c0 = 0.0
        c1 = 3.9450128025e1
        c2 = 2.3622373598e-2
        c3 = -3.2858906784e-4
        c4 = -4.9904828777e-6
        c5 = -6.7509059173e-8
        c6 = -5.7410327428e-10
        c7 = -3.1088872894e-12
        c8 = -1.0451609365e-14
        c9 = -1.9889266878e-17
        c10 = -1.6322697486e-20
        et = 0.0
    
    elif(temp >= 0.0 and temp < 13720.0):
        c0 = -1.7600413686e1
        c1 = 3.8921204975e1
        c2 = 1.8558770032e-2
        c3 = -9.9457592874e-5
        c4 = 3.1840945719e-7
        c5 = -5.6072844889e-10
        c6 = 5.6075059059e-13
        c7 = -3.2020720003e-16
        c8 = 9.7151147152e-20
        c9 = -1.2104721275e-23
        c10 = 0.0
        t = (temp)
        t -= 126.9686
        t = t * t
        t = t * a1
        et = math.exp(t) * a0
    else:
        return 0.0
    t = (temp)
    mikrovolts = c0 + t * (c1 + t * (c2 + t * (c3 + t * (c4 + t * (c5 + t * (c6 + t * (c7 + t * (c8 + t * (c9 + t * (c10)))))))))) + et
    return mikrovolts

# ITS-90 k type thermocouple function to translate microvolts to temperature
def k_type_translate_uv(uV):
    c1 = c2 = c3 = c4 = c5 = c6 = c7 = c8 = c9 = 0.0
    temp = 0.0
    if (uV >= -5891.0 and uV < 0.0):
        c0 = 0
        c1 = 2.5173462e-2
        c2 = -1.1662878e-6
        c3 = -1.0833638e-9
        c4 = -8.9773540e-13
        c5 = -3.7342377e-16
        c6 = -8.6632643e-20
        c7 = -1.0450598e-23
        c8 = -5.1920577e-28
        c9 = 0

        temp = c0 + uV * (c1 + uV * (c2 + uV * (c3 + uV * (c4 + uV * (c5 + uV * (c6 + uV * (c7 + uV * (c8))))))))
    elif (uV >= 0.0 and uV < 20644.0):
        c0 = 0
        c1 = 2.508335e-2
        c2 = 7.860106e-8
        c3 = -2.503131e-10
        c4 = 8.315270e-14
        c5 = -1.228034e-17
        c6 = 9.804036e-22
        c7 = -4.413030e-26
        c8 = 1.057734e-30
        c9 = -1.052755e-35
        
        temp = c0 + uV * (c1 + uV * (c2 + uV * (c3 + uV * (c4 + uV * (c5 + uV * (c6 + uV * (c7 + uV * (c8 + uV * (c9)))))))))


    elif (uV >= 20644.0 and uV < 54886.0):
        c0 = -1.318058e2
        c1 = 4.830222e-2
        c2 = -1.646031e-6
        c3 = 5.464731e-11
        c4 = -9.650715e-16
        c5 = 8.802193e-21
        c6 = -3.110810e-26
        c7 = 0
        c8 = 0
        c9 = 0

        temp = c0 + uV * (c1 + uV * (c2 + uV * (c3 + uV * (c4 + uV * (c5 + uV * (c6))))))
    else:
        temp = -300.0 # OUT OF RANGE deliberately
    return temp




a = 0
ch1_uv = 0.0
result=0

def read_thermocouples():
  # try:
    global a
    global vref
    global vadj
    global led_counter
    global pcb_temp
    a = a + 1
    if a>8:
      os.system("clear") # this is for tunning in a terminal over ssh on a pi
      a = 0
      print_list()
      #time.sleep(0.1)

    time.sleep(0.01)
    # perpare bits for ADC command to read channel 
    cb1 = 4 + 2 + ((a & 4) >> 2)
    cb2 = (a & 3) << 6
    resp = spi.xfer2([cb1, cb2, 0x00])

    if a == 0:
        vref = resp[1] * 256.0 + resp[2] * 1.0
        vadj_now = vref/3355.4432
        vadj = vadj_now * 0.1 + vadj * 0.9
        print "vref: ", vref, "vadj: ", vadj
        channels[a] = vref

        if led_counter<4: 
          GPIO.output(17,GPIO.LOW) # D3 LED ON
          GPIO.output(22,GPIO.HIGH) # D2 LED OFF
        else:
          GPIO.output(17,GPIO.HIGH) # D3 LED OFF
          GPIO.output(22,GPIO.LOW) # D2 LED ON
        led_counter = led_counter + 1
        if led_counter>8:
           led_counter=0
    if a >= 1 and a < 8:
        ch1_adc12_5v = ((resp[1] * 256.0 + resp[2]*1.0) - vref) * vadj
        ch1 = resp[1] * 256.0 + resp[2]*1.0
        perfect = ((vref - ch1) * vadj)
        bigV = (perfect/4096.0)*5.0
        # the signal has been amplified G=100 so we need to multiply by 10K
        uV = bigV*10000
        # now first order filter the micro-volts to reduce random noise
        channels[a] = channels[a]*0.9 + 0.1*uV
    if a == 8: # read the temperature from the tc77
    	resp = spi_tc77.xfer2([0x00, 0x00, 0x00, 0x00]) # transfer four bytes
        number = resp[0] * 256 + resp[1]
	pcb_temp = (number/8.0) * 0.0625
	print "Temp: ", pcb_temp, resp

# set up the gui
#
curtime = ''
curtemp = ''
newtemp = -299.0
timeline = [1,2,3,4,5,6,7]
templine = [1,2,3,4,5,6,7]
templine2 = [1,2,3,4,5,6,7]
timeobj = ''
abs_zero = -273.15


class Window:

  def __init__(self,root):
    self.root = root 
    self.canvas = Tkinter.Canvas(self.root)
    self.canvas.pack()
    self.canvas.config(background='lightblue')
    self.canvas.config(width=500)
    self.canvas.config(height=900)


class TH7gui():
	device = None
	handle = None
	def __init__(self,):
		return None

	def open(self):
		return self.handle

update_gui_counter = 0

def update_gui():
  INTERVAL = 1
  global curtime
  global curtemp
  global timeobj
  global newtemp
  global ybase
  global update_gui_counter
  deg = unichr(176).encode("utf-8")
  read_thermocouples()
  update_gui_counter = update_gui_counter + 1
  #print "update_gui_counter", update_gui_counter
  if update_gui_counter >= 10:
    update_gui_counter  = 0 
    for i in range(7):
            #
            #print 'newtemp' , newtemp
            newtemp = temps[i]
            temps[i] += 0.1 * random.randrange(-10, 20)
            if temps[i] > 500:
                temps[i] = -300
            
            if templine2:
              TH7_window.canvas.delete(templine2[i])
              TH7_window.canvas.delete(templine[i])
            t1 = " %2.2d " % newtemp
            kelvin = newtemp + (-abs_zero);
            
            
            if kelvin >= 273.15 + 40:
              filc = 'pink' # warm
            if kelvin >= 273.15 + 70: # 120oC
              filc = 'red' # hot
            if kelvin < 273.15 + 35:
              filc = 'orange' # human levels of body temperature, go orange
            if kelvin < 273.15 + 24:
              filc = 'grey' # coldish
            if kelvin < 273.15:
              filc = 'blue' # cold
            if kelvin < -15+273.15:
              filc = 'black' # very very cold, like sweden in the winter cold
            
            x1 = 115 + i * 50
            x2 = 125 + i * 50
            y1 =  (ybase)
            y2 = (ybase)-tcompressk(kelvin)
            #y2 =  (ybase)-kelvin
            #print " x1 ",x1, " y1 ", y1, " x2 ", x2, " y2 ", y2
            templine[i] = TH7_window.canvas.create_text(x1, y1+250, text=t1, font=("Helvetica", "12", "bold"), fill='green')
            templine2[i] = TH7_window.canvas.create_rectangle(x1, y1, x2,  y2, fill=filc)
            
            #tll = TH7_window.canvas.create_oval( x1-15, 800+30, x1+25, 800, fill=filc)
    
    #
    #
    y1pos = ybase - tcompressk(0.0)
    templine3 = TH7_window.canvas.create_text ( 55, y1pos, text="-273.15", font=("Helvetica", "18", "bold"), fill='black') 
    templine4 = TH7_window.canvas.create_line ( 55, y1pos, 700, y1pos, fill='grey')
    #
    y1pos = ybase - tcompressk(273.15-200.0)
    templine3 = TH7_window.canvas.create_text ( 55, y1pos, text="-200oC", font=("Helvetica", "18", "bold"), fill='blue') 
    templine4 = TH7_window.canvas.create_line ( 55, y1pos, 700, y1pos, fill='grey')
    #
    y1pos = ybase - tcompressk(273.15-100.0)
    templine3 = TH7_window.canvas.create_text ( 55, y1pos, text="-100"+deg+"C", font=("Helvetica", "18", "bold"), fill='blue') 
    templine4 = TH7_window.canvas.create_line ( 55, y1pos, 700, y1pos, fill='grey')
    #
    y1pos = ybase - tcompressk(273.15-0.0)
    templine3 = TH7_window.canvas.create_text ( 55, y1pos, text="-0oC", font=("Helvetica", "18", "bold"), fill='black') 
    templine4 = TH7_window.canvas.create_line ( 55, y1pos, 700, y1pos, fill='grey')
    #
    y1pos = ybase - tcompressk(273.15+100.0)
    templine3 = TH7_window.canvas.create_text ( 55, y1pos, text="100oC", font=("Helvetica", "18", "bold"), fill='black') 
    templine4 = TH7_window.canvas.create_line ( 55, y1pos, 700, y1pos, fill='grey')
    #
    y1pos = ybase - tcompressk(273.15+200.0)
    templine3 = TH7_window.canvas.create_text ( 55, y1pos, text="200oC", font=("Helvetica", "18", "bold"), fill='red') 
    templine4 = TH7_window.canvas.create_line ( 55, y1pos, 700, y1pos, fill='grey')
    #
    y1pos = ybase - tcompressk(273.15+300.0)
    templine3 = TH7_window.canvas.create_text ( 55, y1pos, text="300oC", font=("Helvetica", "18", "bold"), fill='red') 
    templine4 = TH7_window.canvas.create_line ( 55, y1pos, 700, y1pos, fill='grey')
    #
    y1pos = ybase - tcompressk(273.15+400.0)
    templine3 = TH7_window.canvas.create_text ( 55, y1pos, text="400oC", font=("Helvetica", "18", "bold"), fill='red') 
    templine4 = TH7_window.canvas.create_line ( 55, y1pos, 700, y1pos, fill='grey')
    #
    y1pos = ybase - tcompressk(273.15+600.0)
    templine3 = TH7_window.canvas.create_text ( 55, y1pos, text="600oC", font=("Helvetica", "18", "bold"), fill='red') 
    templine4 = TH7_window.canvas.create_line ( 55, y1pos, 700, y1pos, fill='grey')
    #
    y1pos = ybase - tcompressk(273.15+800.0)
    templine3 = TH7_window.canvas.create_text ( 55, y1pos, text="800oC", font=("Helvetica", "18", "bold"), fill='red') 
    templine4 = TH7_window.canvas.create_line ( 55, y1pos, 700, y1pos, fill='grey')
  
    # get time
    newtime = time.strftime('%y:%m:%d::%H:%M:%S')
    if newtime != curtime:
      curtime = newtime
    #if timeobj:
    #  TH7_window.canvas.delete(time_obj)
    #timeobj = TH7_window.canvas.create_text(400, 40, text=curtime, font=("Helvetica", "48", "bold"), fill='red')
  
  # recall every 10ms but only draw every tenth
  TH7_window.canvas.after(INTERVAL, update_gui)

if __name__ == "__main__":
	root = Tkinter.Tk()
	root.title('TH7 Thermometer Display')
	TH7_window = Window(root)
	update_gui()
	root.mainloop()

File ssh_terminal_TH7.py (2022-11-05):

#!/usr/bin/python

import math
import os
import spidev
import time
import datetime
import RPi.GPIO as GPIO
import numpy as np
import logging
from thermocouples import *


pcb_temp = 25.0

vadj =1.0
vadj_now=1.0
vref=0.0
ch1 = 0.0
a = 0
result=0

pi_vdd=5.0

dt = datetime.datetime.now()
logging.basicConfig(filename='TH7.log',level=logging.DEBUG)
logging.warning('TH7 LOG FILE STARTED ' + dt.__str__() + '\n')

GPIO.setmode(GPIO.BCM)
GPIO.setwarnings(False)
GPIO.setup(22, GPIO.OUT) # D2 LED
GPIO.setup(17, GPIO.OUT) # D3 LED
GPIO.output(22,GPIO.HIGH) # D2 LED OFF
GPIO.output(17,GPIO.LOW) # D3 LED ON

kk=0
pcb_temp = 25.0
channels = [0,0,0,0,0,0,0,0]
class Thermocouple_Channel:

    def __init__(self, channel, filter_level=0, thermocouple_type="uv", offset=0.0, gain=106.2):

        self.channel = channel
        self.filter_level = filter_level
        self.thermocouple_type = thermocouple_type
        self.offset = offset
        self.value_uv = 0.0
        self.gain = gain
        self.value_c = -300.0


# references/pointers to thermocouple_channel objects are stored here
thermocouples = np.array([0, 0, 0, 0, 0, 0, 0], dtype=object)

# initialise array/list with 7 "blanks"
for i in range(0, 7):
    # filter level = -1 indicates the channel is `blank'
    thermocouples[i] = Thermocouple_Channel(i+1, 2, "K", 0, 106.8)



# Here, define each thermocouple channel connected to the TH7/ in use.
# 1st parameter is the No. of the channel; on PCB,
# 2nd is the filtering level, [0..3] (higher is harder filtering)
# 3rd is the T/C type as 1 upper-case character;
# currently supporting types: K, T, J, N, E, B, S


# channel, filter level, type, offset (in oC), gain (default 106)


thermocouples[0] = Thermocouple_Channel(1, 3, "K", -0.0, 106.8)
thermocouples[1] = Thermocouple_Channel(2, 3, "K", -0.0, 106.8)
thermocouples[2] = Thermocouple_Channel(3, 3, "K", -0.0, 106.8)
thermocouples[3] = Thermocouple_Channel(4, 3, "K", -0.0, 106.8)
thermocouples[4] = Thermocouple_Channel(5, 3, "K", -0.0, 106.8)
thermocouples[5] = Thermocouple_Channel(6, 3, "K", -0.0, 106.8)
thermocouples[6] = Thermocouple_Channel(7, 3, "K", -0.0, 106.8)


def write_json_files():
        # temperature file
    test_buffer = "["

    for i in range(0, len(thermocouples)):

        tc_type = thermocouples[i].thermocouple_type
        f_level = thermocouples[i].filter_level
        channel = thermocouples[i].channel
        uv      = thermocouples[i].value_uv
        offset  = thermocouples[i].offset
        gain    = thermocouples[i].gain
        tempc   = thermocouples[i].value_c


        test_buffer += "{\"id\": %d, \"value\": %f, \"filter_level\": %d, \"type\": \"%s\", \"offset\": %f, \"gain\": %f, \"tempc\": %f }" % (i, uv, f_level, tc_type, offset, gain, tempc)
        if (not (i >= len(thermocouples)-1)):
            test_buffer += ","
    test_buffer += "]"

    f = open("thermocouples.json", "w")
    f.write(test_buffer)
    f.close()

    # other info pcb etc
    test_buffer = "["

    test_buffer += "{\"pcb_temp\": %f}," % ( pcb_temp )
    test_buffer += "{\"pivdd\": %f}," % ( pi_vdd )
    test_buffer += "{\"pivadj\": %f}," % ( vadj )
    test_buffer += "{\"pivref\": %f}" % ( vref )

    test_buffer += "]"

    f = open("th7pcbinfo.json", "w")
    f.write(test_buffer)
    f.close()

# first order filters of varying "hardness."
def apply_lag_filter(old_value, new_value, lag_level):
    if lag_level == 0 or lag_level == 1:
        return new_value

	
    if lag_level == 1:
        return ( 0.9 * old_value + 0.1 * new_value )

    if lag_level == 2:
        return ( 0.97 * old_value + 0.03 * new_value )

    if lag_level == 3:
        return ( 0.995 * old_value + 0.005 * new_value )

    # this will change VERY slowly but probably be VERY stable...
    if lag_level == 4:
        return ( 0.9995 * old_value + 0.0005 * new_value )

#
def translate_uv_to_celsius(uv, tc_type="K"):

    if uv is None:
        return -300.0

    uv = uv + 0.0

    if tc_type == "K":
        return K_TYPE_TRANSLATE_UV_TO_C(uv)
    if tc_type == "J":
        return J_TYPE_TRANSLATE_UV_TO_C(uv)
    if tc_type == "N":
        return N_TYPE_TRANSLATE_UV_TO_C(uv)
    if tc_type == "T":
        return T_TYPE_TRANSLATE_UV_TO_C(uv)
    if tc_type == "E":
        return E_TYPE_TRANSLATE_UV_TO_C(uv)
    if tc_type == "B":
        return B_TYPE_TRANSLATE_UV_TO_C(uv)
    if tc_type == "R":
        return R_TYPE_TRANSLATE_UV_TO_C(uv)
    if tc_type == "S":
        return S_TYPE_TRANSLATE_UV_TO_C(uv)

    if tc_type == "uv":
        return -300.0

    return -300.0
#
def translate_celsius_to_uv(c, tc_type="K"):

    if c is None:
        return -300.0

    c = c + 0.0

    if tc_type == "K":
        return K_TYPE_TRANSLATE_C_TO_UV(c)
    if tc_type == "J":
        return J_TYPE_TRANSLATE_C_TO_UV(c)
    if tc_type == "N":
        return N_TYPE_TRANSLATE_C_TO_UV(c)
    if tc_type == "T":
        return T_TYPE_TRANSLATE_C_TO_UV(c)
    if tc_type == "E":
        return E_TYPE_TRANSLATE_C_TO_UV(c)
    if tc_type == "B":
        return B_TYPE_TRANSLATE_C_TO_UV(c)
    if tc_type == "R":
        return R_TYPE_TRANSLATE_C_TO_UV(c)
    if tc_type == "S":
        return S_TYPE_TRANSLATE_C_TO_UV(c)

    if tc_type == "uv":
        return -300.0


    return -300.0
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

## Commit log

2018-09-10 Python program to read seven `k' type thermocouples using the SDS TH7 PCB that fits onto the raspberry pi
2018-09-11 image of unpopulated 0.3 PCB seven channel thermocouple reader for raspberry pi
2018-09-12 User LEDS alternately turned on and off slowly
2018-09-14 Using micro volts adds instead of simpler pcb_temp add for increased accuracY
2018-09-14 display micro-volts as corrected for from zero centigrade
    [k_thermocouples_TH7.py]
2018-09-14 fixed polynomial for > 20.X mV
    [k_thermocouples_TH7.py]
2018-09-28 Mark < 6.5mV as error (this is below abs zero and is picked up by the disconnect protection resistor (if fitted)
    [k_thermocouples_TH7.py]
2018-10-08 OPEN thermo-couple detection description
    OPEN thermo-couple detection description
2018-10-16 TH7 0.4 reading from a K type probe
2018-10-23 Linked spi voltage /tc77 reading code with the thermometer gui
2018-10-25 python global pcb_temp
2019-04-24 added voltage error warning
    [ssh_terminal_TH7.py]
2019-06-16 Fixed timed data logging.
    [TH7_logger.py]
2020-05-12 fixed a few bugs relating to printing microvolt and a few typos in the thermocouples file.
    [thermocouples.py]
2020-05-13 fixed a typo and missing paren
    [thermocouples.py]
2020-05-25 altered filtering startup
2020-06-20 Added configurable gain calibration per channel basis, so that thermocouple channels (independent of type) can be calibrated to within 0.1 degrees celsius.
2020-07-25 Added LED blinking
2021-01-01 fixed json and added error detection -300 oC if uV is too small
    [ssh_terminal_TH7.py]
2021-10-22 kicad files
    [16_25.kicad_pcb, broken.sch, issue01.kicad_pcb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]
2022-10-15 OK got a window with calibration factors working
2022-10-15 bit of syntax checking and confirmation of set calibration
2022-11-05 reindented. also if the micro-volts are out by 1000 reset the filter for the microvolts (uv) rather than on startup
    [ssh_terminal_TH7.py]
2024-11-09 more GUI work can pick settings for each channel etc, needs LOAD/SAVE buttons
2024-11-10 added vref,pcbtemp fields, load and save buttons, submit became reply. Removed pull down on Ch 7 for test, does not appear to alter measurement ie not loaded too harshly (t/c). Note 4.1V is at the OP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
2024-12-07 startup code fix and python3 shebang
    [TH7_tkinter_gui.py]
2025-02-22 kalman filter added as filter 5 now by default
